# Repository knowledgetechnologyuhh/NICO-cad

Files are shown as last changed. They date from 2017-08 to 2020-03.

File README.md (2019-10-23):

# NICO-cad

This git contains the CAD files to 3D-print your own NICO (Neuro Inspired COmpanion) robot.

(https://www.inf.uni-hamburg.de/en/inst/ab/wtm/research/neurobotics/nico.html)

## Academic Citation

If you use the NICO robot, this software or parts of it or the NICO CAD files for your research, please cite the paper 

NICO - Neuro-Inspired COmpanion: A Developmental Humanoid Robot Platform for Multimodal Interaction  
Matthias Kerzel, Erik Strahl, Sven Magg, Nicolás Navarro-Guerrero, Stefan Heinrich, Stefan Wermter
Proceedings of the IEEE International Symposium on Robot and Human Interactive Communication (RO-MAN), pages 113-120, 2017.

> BibTeX Style Citation

```
@InProceedings\{KSMNHW17,
  author       = "Kerzel, Matthias and Strahl, Erik and Magg, Sven and Navarro-Guerrero, Nicol\'as and Heinrich, Stefan and Wermter, Stefan",
  title        = "NICO - Neuro-Inspired COmpanion: A Developmental Humanoid Robot Platform for Multimodal Interaction",
  booktitle    = "Proceedings of the IEEE International Symposium on Robot and Human Interactive Communication (RO-MAN)",
  pages        = "113--120",
  month        = "Aug",
  year         = "2017",
  url          = "https://www2.informatik.uni-hamburg.de/wtm/publications/2017/KSMNHW17/"
}
```
## Documentation

Find all information to run a simulated NICO in the wiki at https://github.com/knowledgetechnologyuhh/NICO-software/wiki

Find much more information and how to build your own NICO at http://nico.knowledge-technology.info

## Credits

### Head

Head based on the iCub design: http://wiki.icub.org/wiki/RobotCub 

Modifications: Added camera holders, added neckholders, added holder for optional xtion camera.

### Ears

Left and right ear based on https://www.thingiverse.com/thing:31843 by https://www.thingiverse.com/Cbonsig/about

Licenses under the "Attribution-ShareAlike 3.0 Unported" license ( https://creativecommons.org/licenses/by-sa/3.0/ )

Modifications: Cut off the original base material for fit on NICO. Added hole for screw.

### Contribuitions by Seed Robotics

Work in the **Optimized for SLS** folder has been contributed by Seed Robotics. Please refer to the README.md file on the folder for fuirther information.

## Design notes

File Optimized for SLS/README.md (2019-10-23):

# NICO-cad (for SLS, Multijet and similar)

This folder contains the CAD files for NiCO  (Neuro Inspired COmpanion) robot, optimized for printing with SLS (or equivalent) technology.  
(Note: if you wish to print the parts using an FDM printer, please refer to the folder with the regular models)

(https://www.inf.uni-hamburg.de/en/inst/ab/wtm/research/neurobotics/nico.html)

For building a NiCO using these models you will need an SLS (or Multijet) 3D Printing service or Machine. You will also need to Lasercut 2 models (5 parts in total).
 
The models in this folder were contributed by Seed Robotics and are based on  the original NiCO design for FDM manufacturing.

Licensed under the "Attribution-ShareAlike 3.0 Unported" license ( https://creativecommons.org/licenses/by-sa/3.0/ ) in compliance with the University of Hamburg's license for the NiCO-CAD files.

###### Design of the parts was modified in the following key areas:

* Improve Reliability (with the use of Lasercut parts and reinforced plastic zones)
* Improve Repeatibility and ease of maintenance regarding the several accessories mounted inside the head
* Improve Camera mounting and focus methods
* Improve Cable routing and management improvements
* Improve Visual/aesthetics
* Optimizations for printing using SLS, Multijet or similar technologies

## Part: Head

The Head of Nico is composed by the main Head part and ears, and, additionally the sub assemblies that hold the cameras, LED matrixes for face expressions, etc.

###### File Description:

* iCub_Face_N(eyes).ipt - Main file with all sub assemblies

(The ears were only available as STL from the beginning; therefore only STL files are available for these models.)

###### STL files ready for print:

* face.stl – Face without any sub assemblies
* camera support.stl – Camera sub assembly
* camera cover.stl (print 2x) – Cover to hold cameras once installed in the Camera Support
* eyebrows support.stl – Support for the two Eyebrow LED matrixes
* mouth support.stl – Support for the mouth LED matrix
* head_support.stl – Back support for mounting the head on the neck, holds the Seed Robotics LED matrix controller and cable management system
* head_cable_clamp.stl – Clamp to secure cables to Support (print 5x)
* ear_right.stl
* ear_left.stl
 

## Part: Neck, Arms and Shoulder

These parts all have individual IPT files.  

Furthermore, for the assembly of the Shoulder, 4x laser cut metal plates are
necessary, which is explained below.

###### File description:

* neck.ipt
* shoulder.ipt
* shoulder_spacer.ipt – spacer to install under the servos that go above the upper plate.
* servo spacer.ipt – gasket to be placed between the Upper plate and the servos that are assembled beneath it.
* upper_arm.ipt
* lower_arm.ipt
* RH4D_hand_base.ipt – the bracket that assembles onto the Seed Robotics RH4D hands for mounting on the lower arm.
* Robotis_cable_clamp.ipt – optional clamp to secure Robotis cables to the MX-64 servos.
* grommet.ipt – for lining of the apertures in the upper plate to reduce cable wear 

For the assembly of the shoulder, it is necessary to manufacture 4x Laser Cut parts.  See the section **“Lasercut parts”**

###### STL files ready for print:

* neck.stl
* servo spacer.stl (print 2x)
* shoulder.stl (print 2x)
* shoulder_spacer.stl (print 2x)
* servo spacer.stl (print 2x)
* upper_arm.stl (print 2x)
* lower_arm.stl (print 2x)
* RH4D_hand_base.stl (print 2x)
* Robotis_cable_clamp.stl (optional; if printing, at least 4x are recommended)
* grommet.stl – ooptional (optional; if printing, at least 4x are recommended)

## Lasercut parts

For the reinforcement of parts where NiCO has shown to be more prone to wear and tear, Laser cut aluminum parts are used.

These should be made from, preferentially, 2mm thick aluminum.

* upper_plate.dxf – the top plate that assembles onto the Makerbeam frame.
* shoulder.dxf : these are necessary to assemble the shoulder 3D printed part. 4x of these should be laser cut for building a NiCO

## Parts not to be 3D printing

* servo holder.ipt - auxiliary file for building many other 3D models. It is referenced (a dependency) of several other models.
*  upper_plate.ipt – for visualization only; use the DXF file for Laser cutting
 

## Further information: Nuts and Bolts

For the assembly of these parts, the following types of Nuts
and bolts are required:

* Hex Nuts M2.5
* Square Nuts M2.5
* Socket screws M2.5 ranging from 4mm to 16mm long  

* Square Nuts M2
* Socket Screws M2x10

* 2.6x8mm Self tapping screws

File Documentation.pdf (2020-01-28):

# Documentation:

# How to print and build your own NICO (CAD)

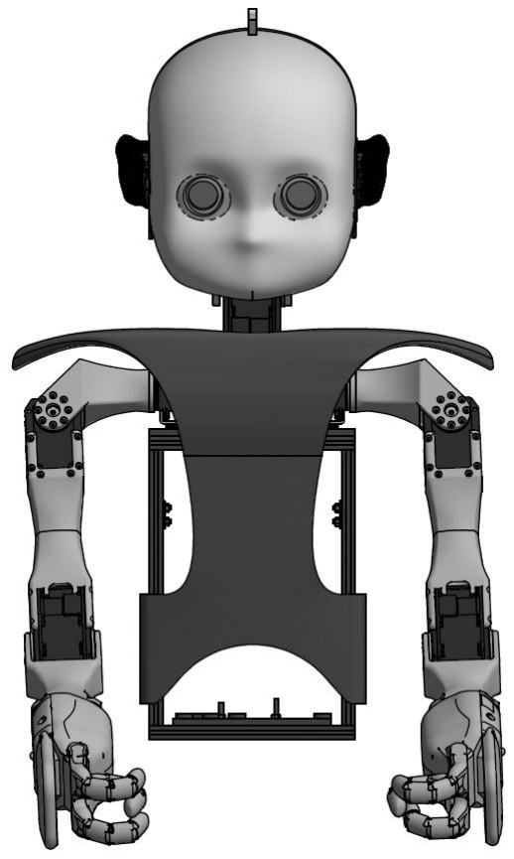
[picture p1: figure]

Christian Wermter

17.12.2019

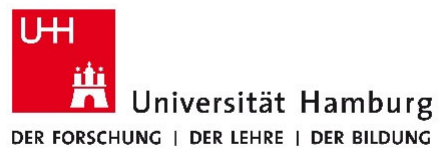
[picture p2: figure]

(This page is purposely left blank)

1) A short Introduction:

This paper is a step by step on how to 3D‐print and build your own NICO (Neuro inspired COmpanion) robot. In the following, we will give an overview of which parts you will have to download and then proceed to go through on how to print the parts and which steps require sharper attention. All parts named in this paper are uploaded in our GitHub NICO‐CAD repository (https://github.com/knowledgetechnologyuhh/NICO‐cad). The files we want to utilize to print the NICO are mostly “xxx.stl” files.

The NICO can be divided into several assembly groups:
- Head
- Body
- Arms
- Neck
- Shoulders
- Cover
- Framework
- Laser cut parts
- Additional Requirements

Frame

All of our self‐printed NICOs are built on and around a frame made out of beams from the toolkit “MakerBeam”.

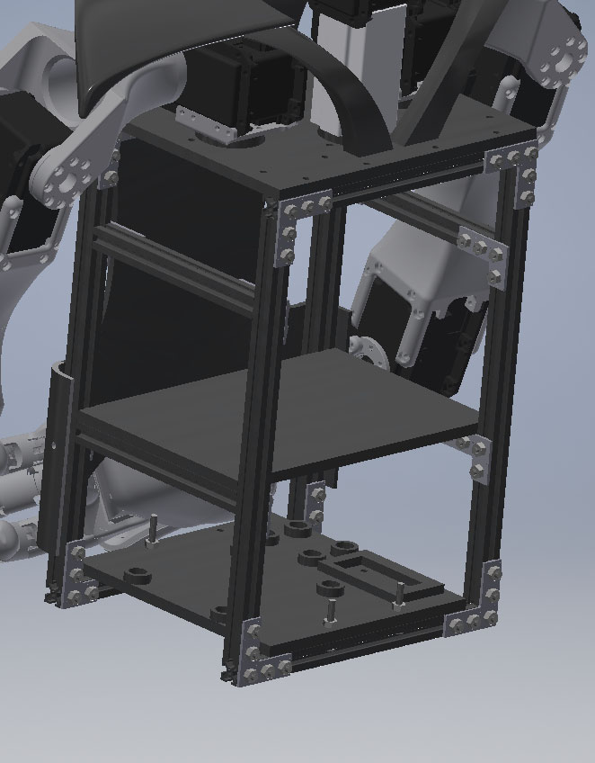
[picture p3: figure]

The frame consists of four 200mm (Art.Nr.100090), four 150mm (100089) and four 100mm (100088) beams connected to one another by 16 right angle brackets (Art.Nr.100326), secured by square headed M3 bolts (6mm, 100359) and M3 nuts.

As seen in the picture above an upper plate is mounted to the top of the framework. The following file is to be 3D‐printed:
- upper_plate.stl

Before placing the upper plate onto the framework, slide in 6mm or 12mm square headed M3 bolts from MakerBeam [Art. Nr. 100359 or 100360]. After placing the upper plate on top of the framework onto the bolts secure the upper plate with M3 nuts.

Head

The head of the NICO mainly consists of the face, the back of the head and the inner support frame. Additionally, ears as well as optionally sub‐assemblies can be printed for holding cables in place, etc.

STL files to be printed:
- face.stl
- spider.stl
- occiput.stl
- ear_left.stl
- ear_right.stl

Optional:
- head_cable_clamp.stl
- several support parts (not essential for first print)

It is mandatory that before printing you open the parts in an stl‐Editor (e.g. Cura) and make required changes to orientation and adjust printing settings to your 3D‐Printers needs. Make sure the orientation of your choice uses least amount of support structure to use printing time and material efficiently.

To assemble the head, take the NICO face and screw and secure the spider to the inside. Then, attach the occiput to complete the head and mount to the tilting motor with M2 bolts.
Arms

To manufacture the arms, the following parts are to be 3D printed:
- upper_arm.stl (2x)
- lower_arm_thick.stl (2x)
- connector.stl (2x)
- shoulder.stl (2x)
- shoulder_spacer.stl (2x)

Motors: Robotis Dynamixel MX64

Starting from the inner body to the outer; The shoulder spacer between motor (vertical axis rotation) and motor (horizontal axis rotation) is there to grant the shoulder enough freedom for rotation. Attached to the horizontal axis rotation motor is the shoulder itself followed by the shoulder‐arm joint motor. Then the upper arm is attached after which the elbow joint motor follows. To the end of the arm the lower arm is followed by the connector, to which the hand (we used the RH5D respectively RH4D versions) is manufactured. All parts are to be connected with the motors with M2 nuts and bolts.

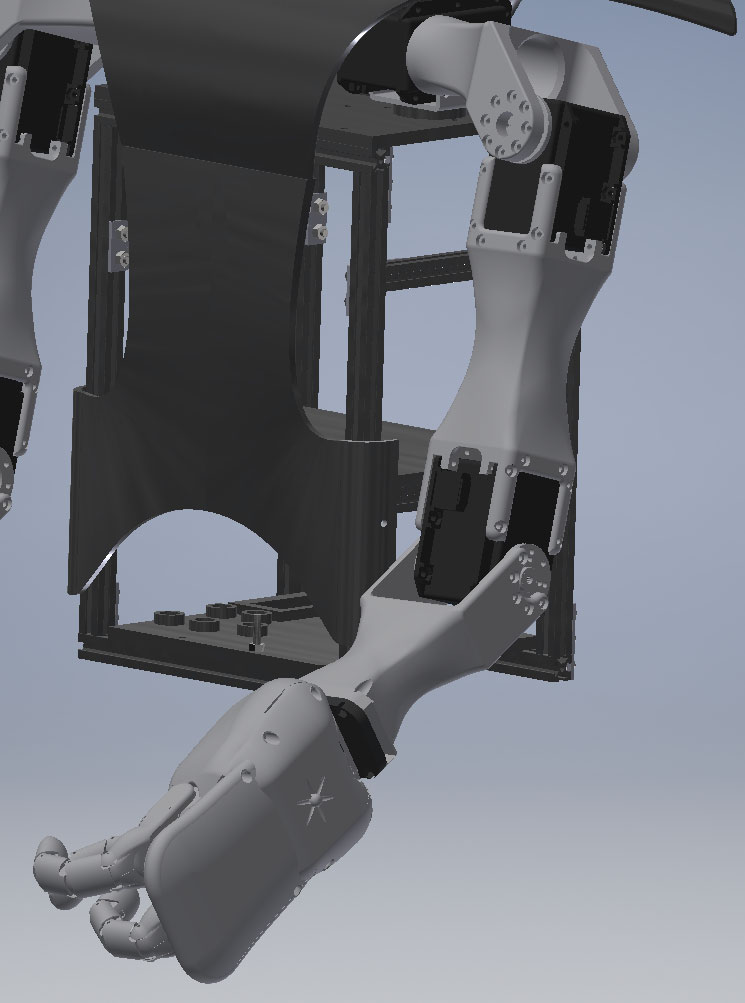
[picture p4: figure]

Neck

The neck is simply just bolted to the shoulder spacer connected to the neck motor. The motor for tilting action of the head is mounted on top of the neck.

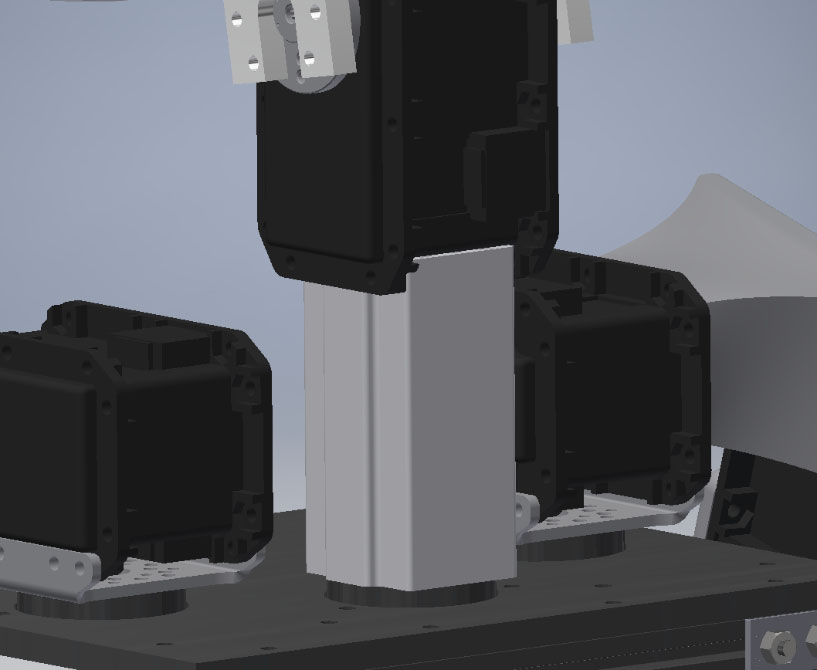
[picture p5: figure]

Shoulder cover

For aesthetics we designed a body and shoulder cover to give the NICO a better appearance to the eye. Additionally, our goal was to design the cover as handy and as practical as possible to ensure a quick mount and demount for the occupant. It is optional for you to print and use and no functionality will be restricted if not.

To mount the shoulders, undo to of the M3 nuts holding the upper plate in place from the front of the NICO. Slide the Shoulders onto the bolts and refasten the shoulders with the M3 nuts. Finally, slide square headed MakerBeam bolts on either outer side of the front beams. Then mount the body cover and fasten with nuts.

Laser cut parts

Due to the fact, that we want to offer an open source NICO, where one only needs a 3D‐printer, we designed all parts to be enduring and stress‐resisting as possible, whilst being 3D‐printed.
If you wish and have the possibility to laser cut parts, you can still use the following dxf.‐files to laser cut specific parts:
- upper_plate.dxf

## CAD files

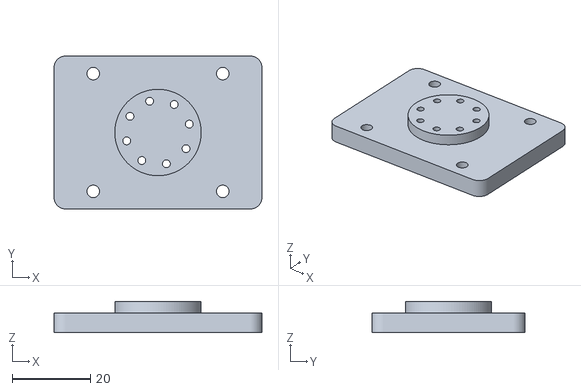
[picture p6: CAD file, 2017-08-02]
hand/connector.stl
53.0 x 39.0 x 8.00

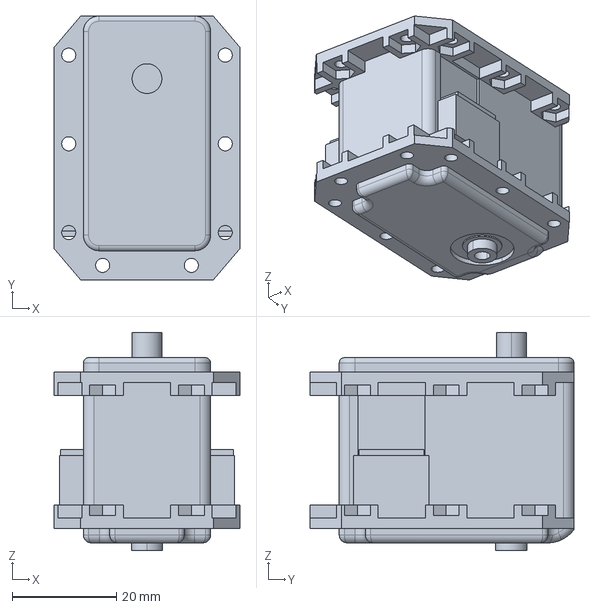
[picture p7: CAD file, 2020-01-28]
motors/Mx28/RX-28.stp
35.6 x 50.6 x 41.9 mm

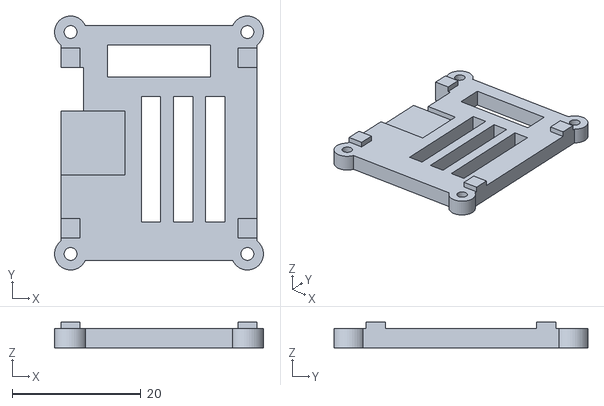
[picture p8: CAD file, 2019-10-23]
Optimized for SLS/camera cover.stl
32.5 x 39.5 x 4.00

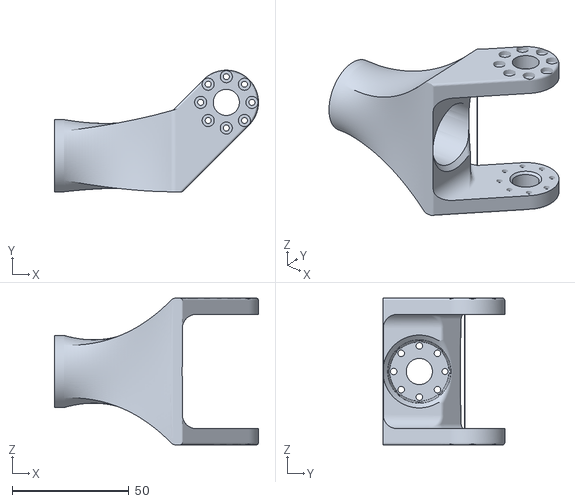
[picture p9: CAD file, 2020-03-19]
stl files/shoulder.stl
87.5 x 52.2 x 63.0

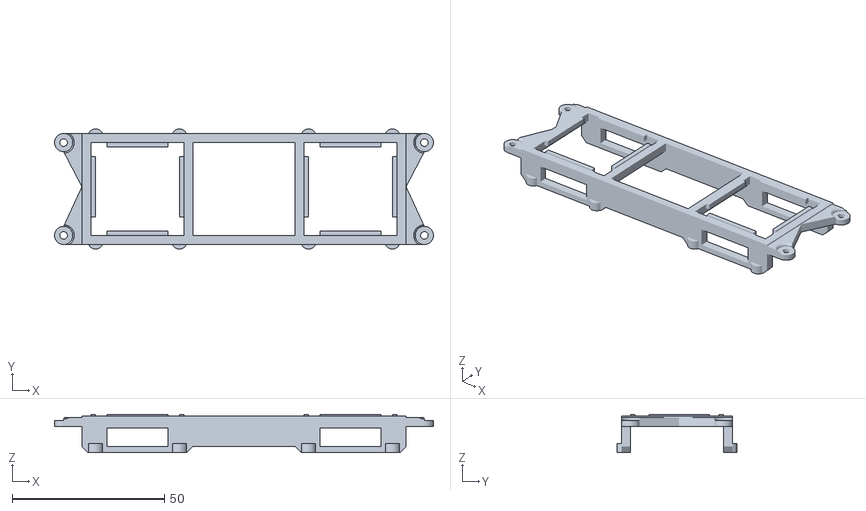
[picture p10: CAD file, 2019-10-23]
Optimized for SLS/camera support.stl
124.5 x 39.5 x 12.5

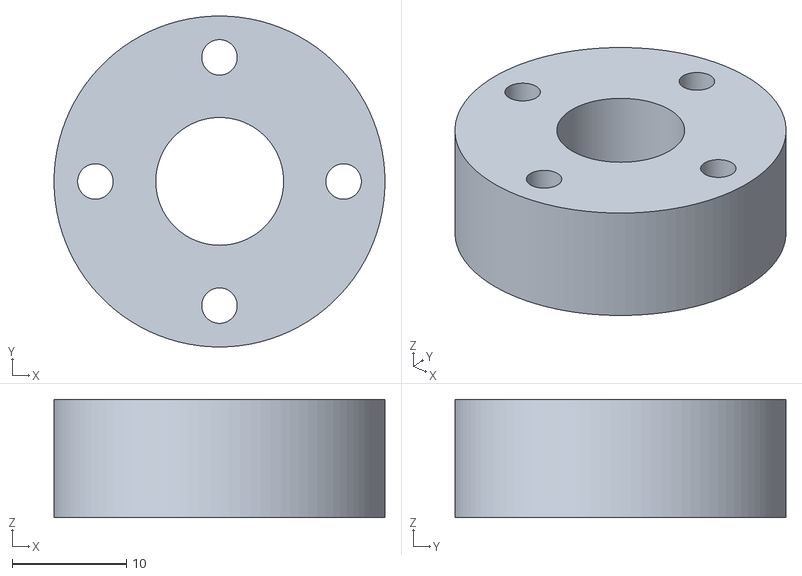
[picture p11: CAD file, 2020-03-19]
stl files/shoulder_spacer.stl
29.0 x 29.0 x 10.4

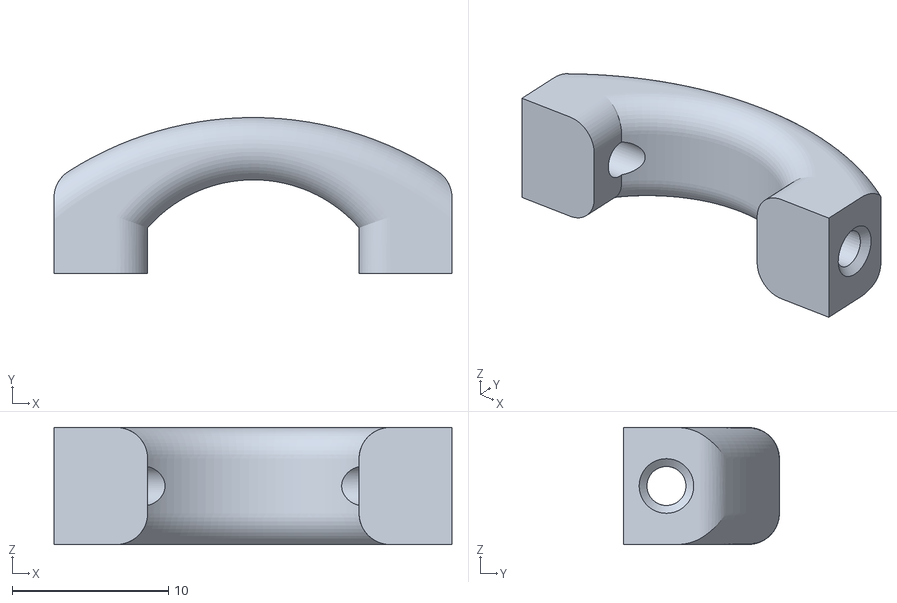
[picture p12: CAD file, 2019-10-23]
Optimized for SLS/Robotis_cable_clamp.stl
25.5 x 9.99 x 7.50

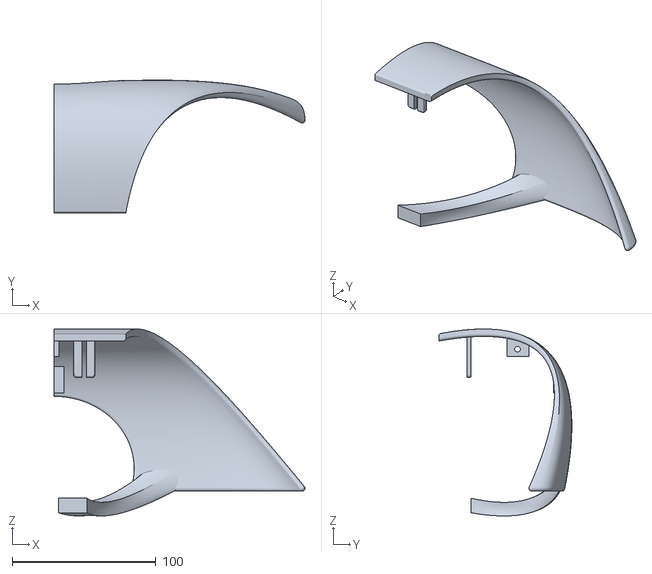
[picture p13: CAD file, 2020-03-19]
stl files/nico_shoulder_cover_left.stl
174.7 x 92.4 x 130.1

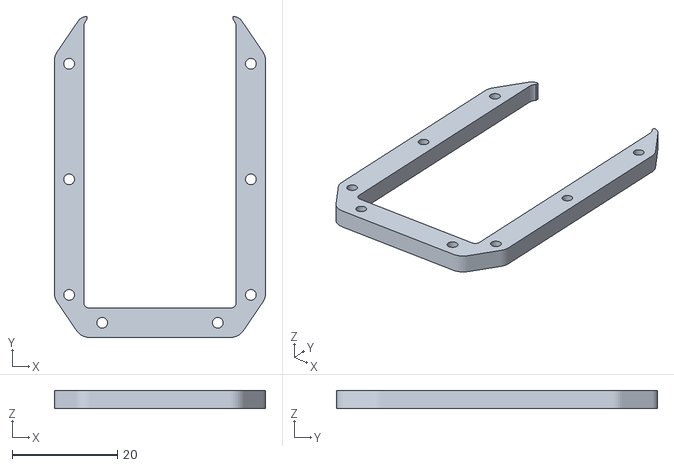
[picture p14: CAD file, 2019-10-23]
Optimized for SLS/servo spacer.stl
40.2 x 61.1 x 3.50

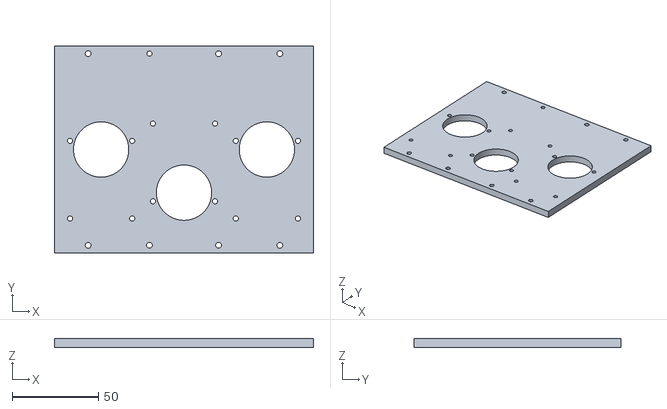
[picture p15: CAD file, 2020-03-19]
stl files/upper_plate.stl
150.0 x 120.0 x 5.00

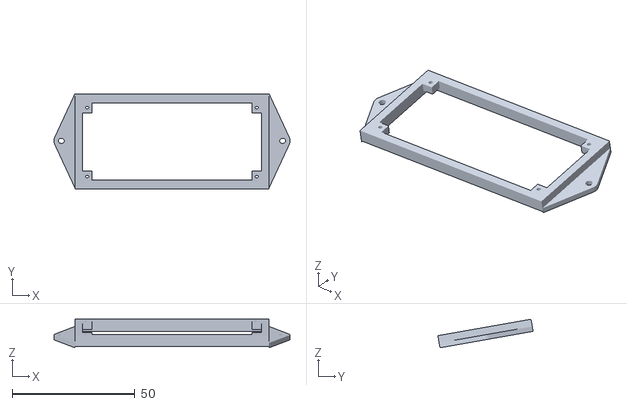
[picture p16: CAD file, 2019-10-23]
Optimized for SLS/mouth support.stl
96.0 x 38.8 x 11.6

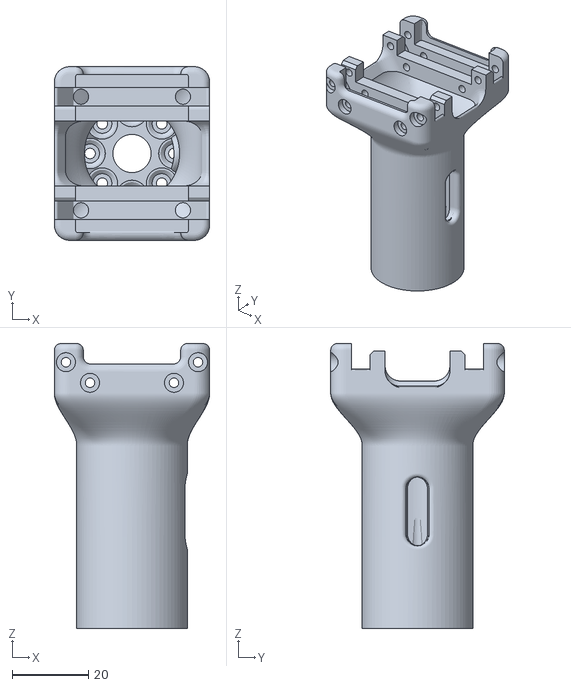
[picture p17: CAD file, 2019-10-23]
Optimized for SLS/neck.stl
40.7 x 45.5 x 74.7

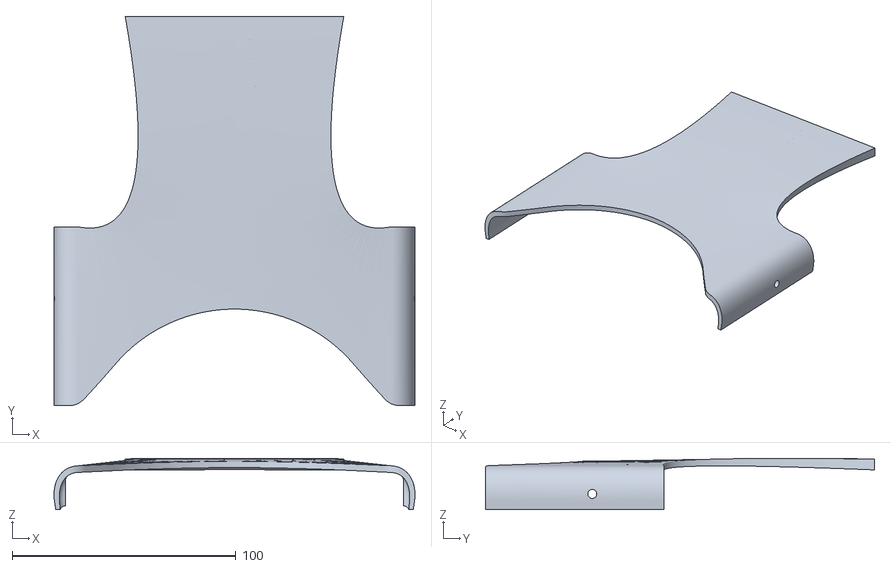
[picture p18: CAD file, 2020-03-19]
stl files/nico_shoulder_cover_body.stl
161.5 x 174.1 x 22.9

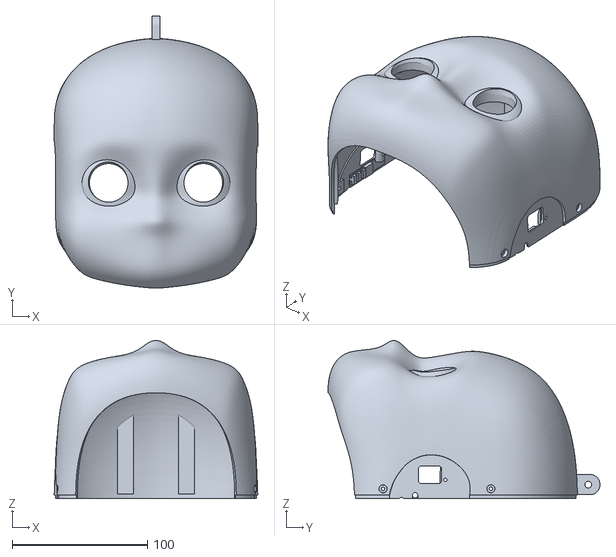
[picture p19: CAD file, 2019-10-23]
Optimized for SLS/face.stl
150.6 x 201.2 x 116.9

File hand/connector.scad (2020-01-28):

$fn=100;

//cylinder(r=10, h=10, center=true, $fn=6);



// size - [x,y,z]
// radius - radius of corners
module roundedRect(size, radius)
{
	x = size[0];
	y = size[1];
	z = size[2];

	linear_extrude(height=z)
	hull()
	{
		// place 4 circles in the corners, with the given radius
		translate([(-x/2)+(radius/2), (-y/2)+(radius/2), 0])
		circle(r=radius);
	
		translate([(x/2)-(radius/2), (-y/2)+(radius/2), 0])
		circle(r=radius);
	
		translate([(-x/2)+(radius/2), (y/2)-(radius/2), 0])
		circle(r=radius);
	
		translate([(x/2)-(radius/2), (y/2)-(radius/2), 0])
		circle(r=radius);
	}
}

difference() {
   union() {
		//cube([50,36,5],center=true);
		roundedRect([50, 36, 5], 3);
	   cylinder(r=11, h=6.5, center=false);
	}		

	
   rotate([0, 0, -30])
   {

	  for(i=[0:7]) {
		 rotate([0, 0, i*360/8]) translate([16.5/2, 0, 0]) cylinder(r=1, h=50, center=true);
	  }

      
   }
   translate([16.5, 15, 0]) cylinder(r=1.2, h=100, center=true);
   translate([-16.5, 15, 0]) cylinder(r=1.2, h=100, center=true);
   translate([16.5, -15, 0]) cylinder(r=1.2, h=100, center=true);
   translate([-16.5, -15, 0]) cylinder(r=1.2, h=100, center=true);
   
   
	
}

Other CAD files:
stl files/nico_shoulder_cover_right.stl
stl files/ear_right.STL
Optimized for SLS/grommet.stl
stl files/ear_left.STL
Optimized for SLS/RH4D_hand_base.ipt
Optimized for SLS/RH4D_hand_base.stl
Optimized for SLS/Robotis_cable_clamp.ipt
Optimized for SLS/eyebrows support.stl
Optimized for SLS/grommet.ipt
Optimized for SLS/head_cable_clamp.stl
Optimized for SLS/head_support.stl
Optimized for SLS/lower_arm.ipt
Optimized for SLS/lower_arm.stl
Optimized for SLS/neck.ipt
Optimized for SLS/servo holder.ipt
Optimized for SLS/servo spacer.ipt
Optimized for SLS/shoulder.dxf
Optimized for SLS/shoulder.ipt
Optimized for SLS/shoulder.stl
Optimized for SLS/shoulder_spacer.ipt
Optimized for SLS/shoulder_spacer.stl
Optimized for SLS/upper plate.dxf
Optimized for SLS/upper plate.ipt
Optimized for SLS/upper_arm.ipt
Optimized for SLS/upper_arm.stl
arms/Lower_Arm_Connector.iam
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

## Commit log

2017-08-02 Initial Nico CAD
    [connector.ipt, connector.stl, frontplate.ipt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]
2018-11-06 Added NICO ears
    [ear_left_cut.stl, ear_right_cut.stl]
2018-11-07 Upper plate and shoulder spacer added
    [shoulder_spacer.stl, upper_plate.stl]
2019-03-22 New Eyes & demountable frame
    [NicoHead_Back.stl]
2019-04-10 Shoulder Covers
    Left and right shoulder covers
    [left_shoulder_cover.stl, right_shoulder_cover.stl]
2019-05-09 New round headnickholder
    [headnickholder_round.iam, headnickholder_round.stl]
2019-09-26 Uploaded Optimized files for SLS printing by Seed Robotics. All models built and validated.
    [RH4D_hand_base.ipt, RH4D_hand_base.stl, Robotis_cable_clamp.ipt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]
